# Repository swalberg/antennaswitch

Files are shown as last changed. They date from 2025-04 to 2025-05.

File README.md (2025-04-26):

# Remote antenna switch

This is a remote controller for one of those DIY antenna switch kits. It listens on Wifi for commands and controls the relays. They take a +12V signal to one of 4 relays with a common ground to pick which port is active, and ground the rest:

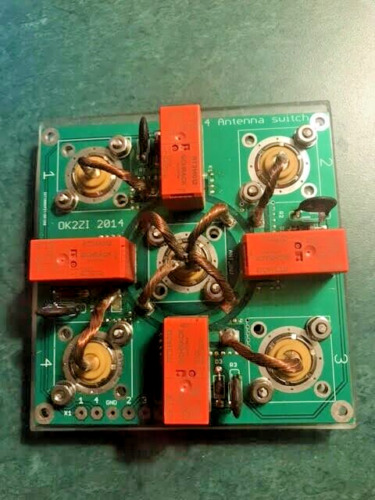
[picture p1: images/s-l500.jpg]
example antenna switch


The firmware for this allows both manual control, and to listen to N1MM+/RUMLogNG broadcasts to pick the band based on configured port/band combinations.

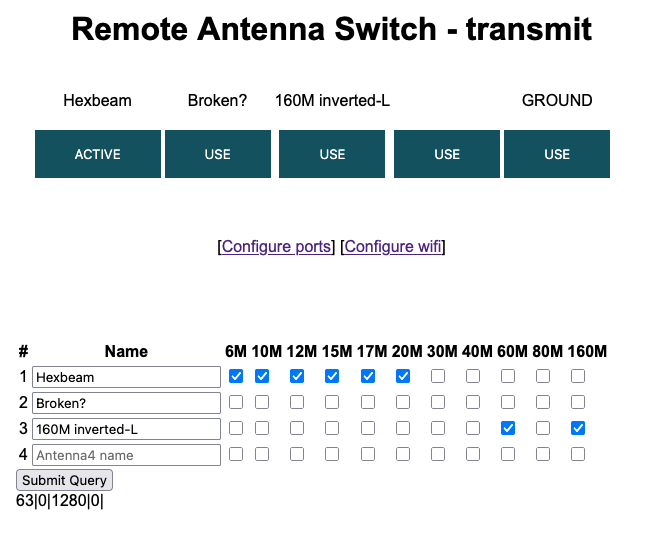
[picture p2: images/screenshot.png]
screenshots


When the device boots without a config it'll start a new AP for you to configure it.

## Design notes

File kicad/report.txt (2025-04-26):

Warning: Width correction constrained.  The width correction value must be in the range of [0.000001 mm; 0.199999 mm] for the current design rules.
Plotted to '/Users/sean/Documents/KiCad/8.0/projects/RemoteAntennaSwitch/outputs/RemoteAntennaSwitch-F_Cu.gbr'.
Plotted to '/Users/sean/Documents/KiCad/8.0/projects/RemoteAntennaSwitch/outputs/RemoteAntennaSwitch-B_Cu.gbr'.
Plotted to '/Users/sean/Documents/KiCad/8.0/projects/RemoteAntennaSwitch/outputs/RemoteAntennaSwitch-F_Paste.gbr'.
Plotted to '/Users/sean/Documents/KiCad/8.0/projects/RemoteAntennaSwitch/outputs/RemoteAntennaSwitch-B_Paste.gbr'.
Plotted to '/Users/sean/Documents/KiCad/8.0/projects/RemoteAntennaSwitch/outputs/RemoteAntennaSwitch-F_Silkscreen.gbr'.
Plotted to '/Users/sean/Documents/KiCad/8.0/projects/RemoteAntennaSwitch/outputs/RemoteAntennaSwitch-B_Silkscreen.gbr'.
Plotted to '/Users/sean/Documents/KiCad/8.0/projects/RemoteAntennaSwitch/outputs/RemoteAntennaSwitch-F_Mask.gbr'.
Plotted to '/Users/sean/Documents/KiCad/8.0/projects/RemoteAntennaSwitch/outputs/RemoteAntennaSwitch-B_Mask.gbr'.
Plotted to '/Users/sean/Documents/KiCad/8.0/projects/RemoteAntennaSwitch/outputs/RemoteAntennaSwitch-Edge_Cuts.gbr'.
Created Gerber job file '/Users/sean/Documents/KiCad/8.0/projects/RemoteAntennaSwitch/outputs/RemoteAntennaSwitch-job.gbrjob'.
Info: Done.

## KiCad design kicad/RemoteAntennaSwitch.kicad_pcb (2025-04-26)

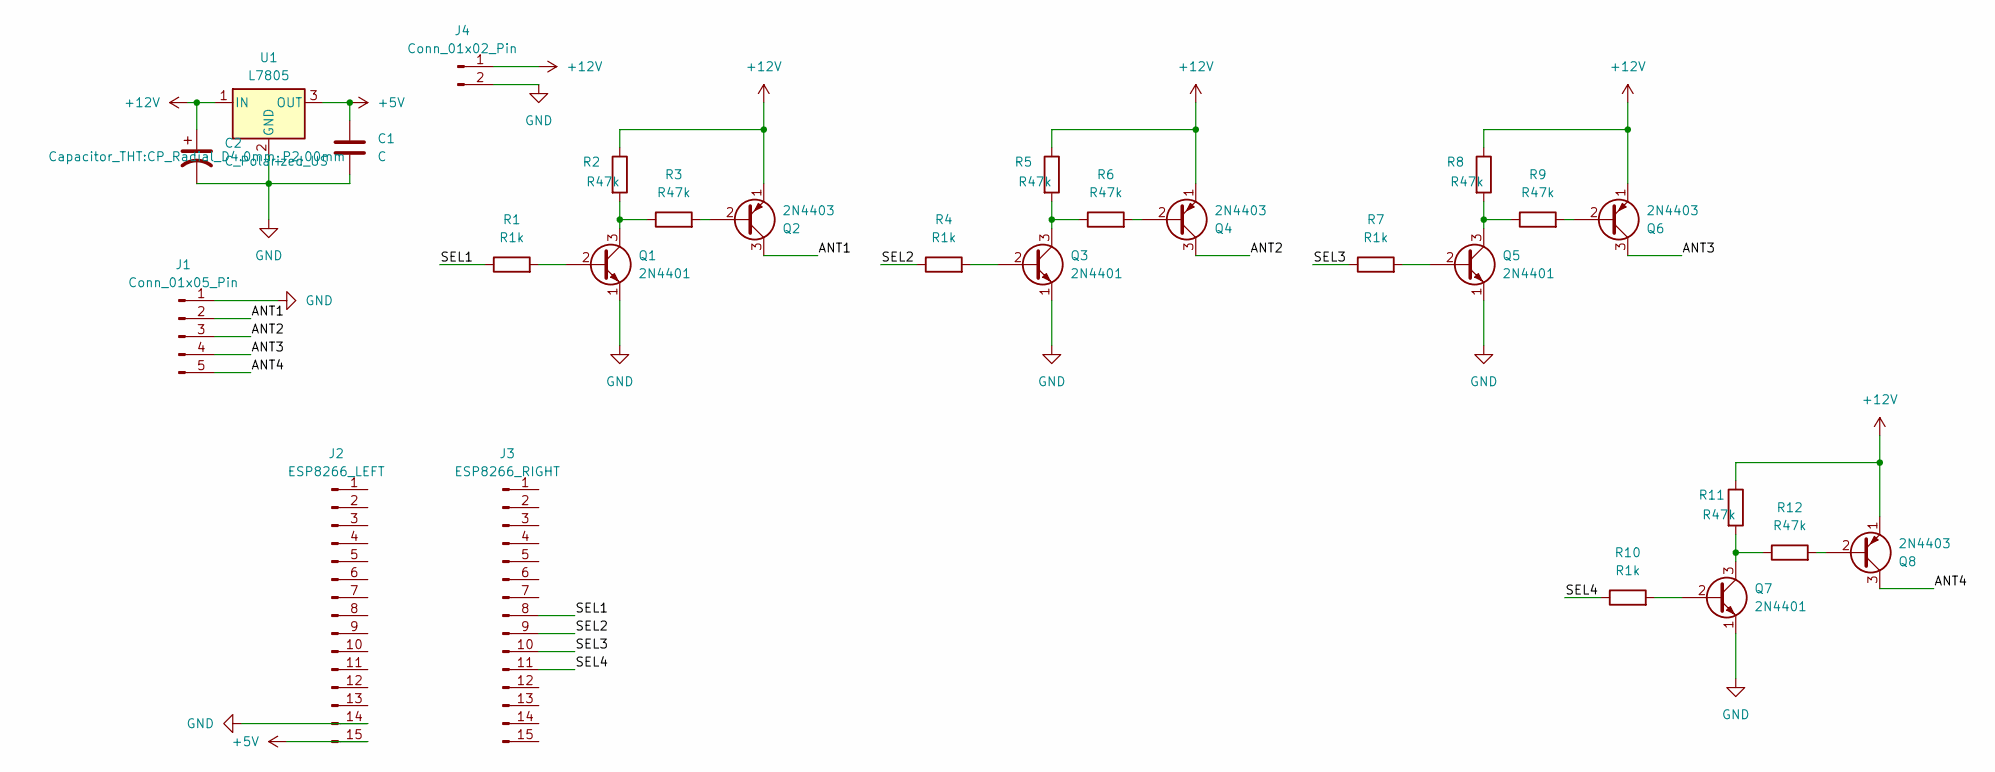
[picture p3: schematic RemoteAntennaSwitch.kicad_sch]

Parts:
C1: C; C_Disc_D3.0mm_W1.6mm_P2.50mm
C2: C_Polarized_US; CP_Radial_D4.0mm_P2.00mm
J1: Conn_01x05_Pin; JST_EH_B5B-EH-A_1x05_P2.50mm_Vertical
J2: ESP8266_LEFT; PinHeader_1x15_P1.00mm_Vertical
J3: ESP8266_RIGHT; PinHeader_1x15_P1.00mm_Vertical
J4: Conn_01x02_Pin; PinHeader_1x02_P1.00mm_Vertical
Q1, Q3, Q5, Q7: 2N4401; TO-92_Inline
Q2, Q4, Q6, Q8: 2N4403; TO-92_Inline
R1, R4, R7, R10: R1k; R_Axial_DIN0204_L3.6mm_D1.6mm_P1.90mm_Vertical
R2, R3, R5, R6, R8, R9, R11, R12: R47k; R_Axial_DIN0204_L3.6mm_D1.6mm_P1.90mm_Vertical
U1: L7805; TO-220-3_Vertical

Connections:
+5V: C1.1, J2.15, U1.3 (OUT)
+12V: C2.1, J4.1, Q2.1 (E), Q4.1 (E), Q6.1 (E), Q8.1 (E), R2.1, R5.1, R8.1, R11.1, U1.1 (IN)
/ANT1: J1.2, Q2.3 (C)
/ANT2: J1.3, Q4.3 (C)
/ANT3: J1.4, Q6.3 (C)
/ANT4: J1.5, Q8.3 (C)
/SEL1: J3.8, R1.1
/SEL2: J3.9, R4.1
/SEL3: J3.10, R7.1
/SEL4: J3.11, R10.1
GND: C1.2, C2.2, J1.1, J2.14, J4.2, Q1.1 (E), Q3.1 (E), Q5.1 (E), Q7.1 (E), U1.2 (GND)
unnamed: Q1.2 (B), R1.2
unnamed: Q1.3 (C), R2.2, R3.1
unnamed: Q2.2 (B), R3.2
unnamed: Q3.2 (B), R4.2
unnamed: Q3.3 (C), R5.2, R6.1
unnamed: Q4.2 (B), R6.2
unnamed: Q5.2 (B), R7.2
unnamed: Q5.3 (C), R8.2, R9.1
unnamed: Q6.2 (B), R9.2
unnamed: Q7.2 (B), R10.2
unnamed: Q7.3 (C), R11.2, R12.1
unnamed: Q8.2 (B), R12.2

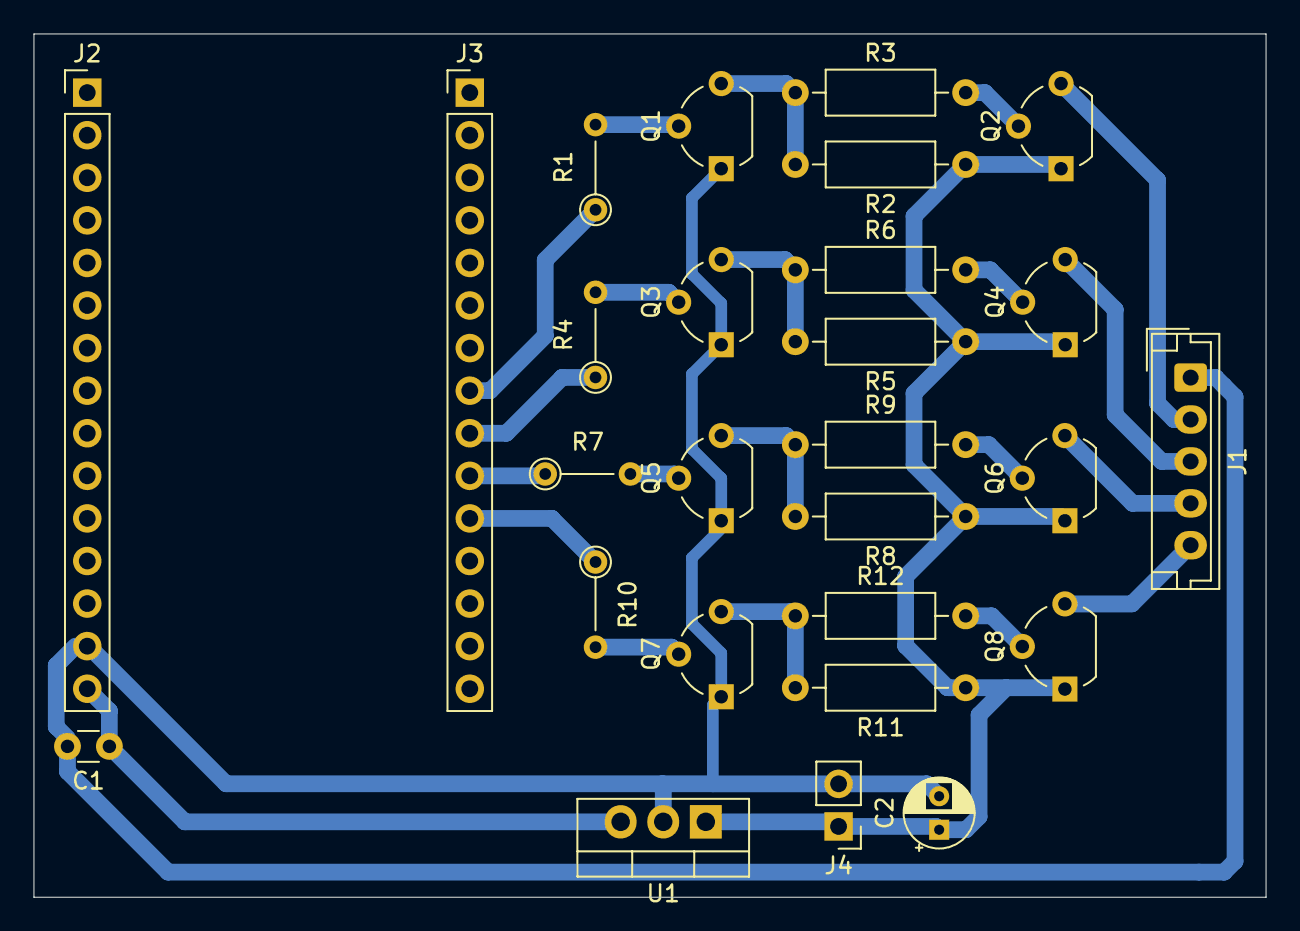
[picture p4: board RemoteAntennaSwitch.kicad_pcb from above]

Board: 2 copper layers, 73.5 x 51.5 mm, 27 parts (0 on the bottom side), 23 nets.

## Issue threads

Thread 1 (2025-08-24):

Doesn't work if it boots to no network

swalberg, 2025-08-24:
If there's a power outage then this device comes up before the wifi and just sits there in SoftAP mode. I have code in there to deal with it (I thought) but it doesn't seem to work.

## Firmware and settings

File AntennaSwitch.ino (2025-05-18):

#include <ArduinoOTA.h>
#include <EEPROM.h>
#include <ESP8266WiFi.h>
#include <ESPAsyncTCP.h>
#include <ESPAsyncWebServer.h>
#include <ESP8266mDNS.h>
#include <TinyXML.h>
#include <WebSerial.h>
#include <WiFiUdp.h>
#include "pages.h"

const int NUM_BANDS = 11;
enum Bands {
  B_6,
  B_10,
  B_12,
  B_15,
  B_17,
  B_20,
  B_30,
  B_40,
  B_60,
  B_80,
  B_160,
  B_unknown
};
Bands manualLocked = B_unknown;
Bands currentBand = B_unknown;

const int MAX_UDP_PACKET_SIZE = 255;
const unsigned long UNCONFIGURED_LIFE = 5 * 60 * 1000;  // 5 minute timer while unconfigured
WiFiUDP UDPInfo;
unsigned int localUdpPort = 12060;
char incomingPacket[MAX_UDP_PACKET_SIZE + 1];
TinyXML xml;
uint8_t buffer[150];  // For XML decoding
bool eligibleForRestart = false;

#define DEFAULT_HOSTNAME "antennaswitch1"
int pins[4] = { 15, 12, 14, 13 };  // The ports on the ESP8266 don't line up to the ports on the switcher because they're out of order and I didn't notice.
int LED = 2;
struct Antenna {
  char label[30];
  byte priority;
  int bands;
};

struct Configuration {
  char hostname[25];
  char ssid[32];
  char password[64];
  Antenna antennas[4];
} config;

// Set web server port number to 80
AsyncWebServer server(80);

int loops = 0;
int activePort = 0;

// Variable to store the HTTP request
String request;
String flashMessage;

void setup() {
  Serial.begin(115200);
  readConfig(config);
  WiFi.begin(config.ssid, config.password);
  for (int i = 0; i < 4; i++) {
    pinMode(pins[i], OUTPUT);
  }
  UDPInfo.begin(localUdpPort);
  // set up xml processing
  xml.init((uint8_t*)buffer, sizeof(buffer), &XML_callback);

  if (testWifi()) {
    Serial.println("Succesfully Connected!!!");
    // Print local IP address and start web server
    Serial.print("IP address: ");
    Serial.println(WiFi.localIP());
  } else {
    WiFi.mode(WIFI_STA);
    WiFi.disconnect();
    delay(100);
    WiFi.softAP("switchconfig", "");
    eligibleForRestart = true;
  }
  setupOta();
  setupRoutes();
  WebSerial.begin(&server);
  WebSerial.msgCallback(receiveSerialMessage);
  server.begin();
}

void loop() {
  ArduinoOTA.handle();
  handleXMLPacket();

  // If we've been sitting around in a state where we might have come up before wifi for too long, restart
  if (eligibleForRestart && millis() > UNCONFIGURED_LIFE) {
    ESP.reset();
  }
}

// If there's no value (default 255) in the first position, we've never been configured
bool isConfigured() {
  return EEPROM.read(0) != 255;
}

// are we connected to a wifi AP?
bool isWifiConnected() {
  return (WiFi.status() == WL_CONNECTED);
}

bool testWifi(void) {
  int c = 0;
  if (!isConfigured()) {
    return false;
  }

  Serial.println("Waiting for Wifi to connect");
  while (c < 20) {
    if (isWifiConnected()) {
      return true;
    }
    delay(500);
    Serial.print("*");
    c++;
  }
  Serial.println("");
  Serial.println("Connect timed out, opening AP");
  return false;
}

// UDP processing of port 12060
void handleXMLPacket() {
  // we've received something, so even if we're unconfigured, we must be on a network with a radio so don't restart automatically
  eligibleForRestart = false;

  int packetSize = UDPInfo.parsePacket();
  if (packetSize) {
    int len = UDPInfo.read(incomingPacket, MAX_UDP_PACKET_SIZE);
    xml.reset();
    for (int i = 0; i < len; i++) {
      xml.processChar(incomingPacket[i]);
    }
  }
}

void XML_callback(uint8_t statusflags, char* tagName, uint16_t tagNameLen, char* data, uint16_t dataLen) {
  if (!(statusflags & STATUS_TAG_TEXT)) {
    return;  // only care about getting the tag data
  }
  if (!strcasecmp(tagName, "/RadioInfo/Freq")) {
    WebSerial.printf("Received Packet to change to band %d which is antenna %d\n", band(atoi(data)), findBestAntenna(band(atoi(data))));
    currentBand = band(atoi(data));
    if (currentBand != manualLocked) {
      // switched bands on the radio, leave locked mode
      manualLocked = B_unknown;
      int antenna = findBestAntenna(currentBand);
      if (antenna >= 0) {
        WebSerial.printf("Switching to antenna %d\n", antenna);
        moveTo(antenna);
      }
    }
  }
}

int findBestAntenna(Bands band) {
  int c = 1 << band;
  for (int i = 0; i < 4; i++) {
    //WebSerial.printf("checking antenna %d which has bands %d against %d, result is %d\n", i, config.antennas[i].bands, c, config.antennas[i].bands & c);
    if ((config.antennas[i].bands & c) > 0) {
      return i;
    }
  }
  return -1;
}

// Web serial callback for input. Doesn't do anything for now
void receiveSerialMessage(uint8_t* data, size_t len) {
  WebSerial.println("Received Web Data...");
  String d = "";
  for (int i = 0; i < len; i++) {
    d += char(data[i]);
  }
  WebSerial.println(d);
}

void setupRoutes() {
  // Route for root / web page
  server.on("/", HTTP_GET, [](AsyncWebServerRequest* request) {
    request->send_P(200, "text/html", index_html, processor);
    WebSerial.println("Root page request");
  });

  server.on("/status.json", HTTP_GET, [](AsyncWebServerRequest* request) {
    request->send_P(200, "application/json", status_json, processor);
  });

  server.on("/config_wifi", HTTP_GET, [](AsyncWebServerRequest* request) {
    request->send_P(200, "text/html", config_wifi, wifi_processor);
  });
  server.on("/config_wifi", HTTP_POST, [](AsyncWebServerRequest* request) {
    if (request->hasParam("ssid", true) && request->hasParam("pass", true)) {
      strcpy(config.hostname, request->getParam("hostname", true)->value().c_str());
      strcpy(config.ssid, request->getParam("ssid", true)->value().c_str());
      strcpy(config.password, request->getParam("pass", true)->value().c_str());
      writeConfig(config);

      request->send(200, "application/json", "{\"Success\":\"saved to eeprom... resetting to boot into new wifi\"}");
      ESP.reset();
    } else {
      request->send(409, "application/json", "{\"Error\":\"Missing a ssid and password\"}");
    }
  });

  server.on("/config", HTTP_GET, [](AsyncWebServerRequest* request) {
    request->send_P(200, "text/html", config_html, processor);
  });

  server.on("/config", HTTP_POST, [](AsyncWebServerRequest* request) {
    for (int i = 0; i < 4; i++) {
      String rvar = "ant";
      rvar += i;
      // Label
      if (request->hasParam(rvar, true)) {
        strcpy(config.antennas[i].label, request->getParam(rvar, true)->value().c_str());
      }
      config.antennas[i].bands = 0;  // we only get in values that are set, so start from nothing and build up
      int c = 1;
      for (int b = 0; b < NUM_BANDS; b++) {
        String band = "band_";
        band += i;
        band += "_";
        band += b;
        if (request->hasParam(band, true)) {
          if (request->getParam(band, true)->value() == "on") {
            config.antennas[i].bands |= c;  // set the bit, we support this band.
          }
        }
        c *= 2;
      }
    }

    writeConfig(config);
    request->redirect("/config");
  });

  server.on("/change", HTTP_GET, [](AsyncWebServerRequest* request) {
    if (request->hasParam("ant")) {
      manualLocked = currentBand;  // Save the current band because we are locked to this antenna for this band
      moveTo(atoi(request->getParam("ant")->value().c_str()));
      WebSerial.println("Changing to " + request->getParam("ant")->value());
      request->send(200, "text/html", "{\"status\": \"ok\"}");
    } else {
      WebSerial.println("I got asked to move but no antenna given");
      request->send(412, "text/html", "{\"status\": \"need an antenna\"}");
    }
  });

  server.on("/debug", HTTP_GET, [](AsyncWebServerRequest* request) {
    request->send_P(200, "text/html", debug_html, processor);
  });

  server.on("/on", HTTP_GET, [](AsyncWebServerRequest* request) {
    manualLocked = currentBand;  // lock it!
    if (request->hasParam("ant")) {
      WebSerial.println("on - " + request->getParam("ant")->value());

      digitalWrite(pins[atoi(request->getParam("ant")->value().c_str())], HIGH);
      request->send(200, "text/html", "{\"status\": \"ok\"}");

    } else {
      request->send(412, "text/html", "{\"status\": \"need an antenna\"}");
    }
  });

  server.on("/off", HTTP_GET, [](AsyncWebServerRequest* request) {
    manualLocked = currentBand;  // lock it!
    if (request->hasParam("ant")) {
      WebSerial.println("off - " + request->getParam("ant")->value());
      digitalWrite(pins[atoi(request->getParam("ant")->value().c_str())], LOW);
      request->send(200, "text/html", "{\"status\": \"ok\"}");

    } else {
      request->send(412, "text/html", "{\"status\": \"need an antenna\"}");
    }
  });
}
void moveTo(int port) {
  WebSerial.printf("> %d\n", port);
  for (int i = 0; i < 4; i++) {
    digitalWrite(pins[i], port == i ? HIGH : LOW);
  }
  activePort = port;
}

// Replaces placeholders in a page with dynamic info
String processor(const String& var) {

  if (var == "ANTENNA0") { return String(config.antennas[0].label); }
  if (var == "ANTENNA1") { return String(config.antennas[1].label); }
  if (var == "ANTENNA2") { return String(config.antennas[2].label); }
  if (var == "ANTENNA3") { return String(config.antennas[3].label); }
  if (var == "ANTENNA0BANDS") { return checkboxes(0); }
  if (var == "ANTENNA1BANDS") { return checkboxes(1); }
  if (var == "ANTENNA2BANDS") { return checkboxes(2); }
  if (var == "ANTENNA3BANDS") { return checkboxes(3); }
  if (var == "ACTIVE_NUMBER") { return String(activePort); }
  if (var == "SWITCH_NAME") { return String("transmit"); }
  if (var == "FLASH_MESSAGE") { return String(flashMessage); }
  if (var == "MANUAL") { return manualLocked == B_unknown ? "false" : "true"; }
  if (var == "DEBUG") {
    String d = "";
    for (int i = 0; i < 4; i++) {
      d += config.antennas[i].bands;
      d += "|";
    }
    return d;
  }

  return String();  // default
}

// template vars for wifi setup
String wifi_processor(const String& var) {
  if (var == "FOUND_NETWORKS") {
    return String("Network scanning disabled...");
  }
  if (var == "xxxFOUND_NETWORKS") {
    int n = WiFi.scanNetworks();
    Serial.printf("There are %d networks\n", n);
    if (n == 0) {
      Serial.println("no networks found");
      return String("No networks found.");
    } else {
      String foundNetworks = String("<ol>");
      for (int i = 0; i < n; i++) {
        // Print SSID and RSSI for each network found
        foundNetworks += "<li>";
        foundNetworks += WiFi.SSID(i);
        foundNetworks += " (";
        foundNetworks += WiFi.RSSI(i);

        foundNetworks += ")";
        foundNetworks += (WiFi.encryptionType(i) == ENC_TYPE_NONE) ? " " : "*";
        foundNetworks += "</li>";
      }
      foundNetworks += "</ol>";
      return (foundNetworks);
    }
  }

  return String();  //default
}

String checkboxes(int ant) {
  String out = "";
  int c = 1;  // compare bit
  for (int i = 0; i < NUM_BANDS; i++) {
    String value = "";

    if ((config.antennas[ant].bands & c) > 0) {
      value += "checked";
    }
    out += String("<td><input type=\"checkbox\" name =\"band_");
    out += ant;
    out += "_";
    out += i;
    out += "\" " + value + "></td>";
    c *= 2;
  }
  return out;
}

void setupOta() {
  // Hostname defaults to esp8266-[ChipID]
  ArduinoOTA.setHostname(getHostname());

  // No authentication by default
  // ArduinoOTA.setPassword((const char *)"123");

  ArduinoOTA.onStart([]() {
    Serial.println("Start");
  });
  ArduinoOTA.onEnd([]() {
    Serial.println("\nEnd");
  });
  ArduinoOTA.onProgress([](unsigned int progress, unsigned int total) {
    Serial.printf("Progress: %u%%\r", (progress / (total / 100)));
  });
  ArduinoOTA.onError([](ota_error_t error) {
    Serial.printf("Error[%u]: ", error);
    if (error == OTA_AUTH_ERROR) Serial.println("Auth Failed");
    else if (error == OTA_BEGIN_ERROR) Serial.println("Begin Failed");
    else if (error == OTA_CONNECT_ERROR) Serial.println("Connect Failed");
    else if (error == OTA_RECEIVE_ERROR) Serial.println("Receive Failed");
    else if (error == OTA_END_ERROR) Serial.println("End Failed");
  });
  ArduinoOTA.begin();
}

char* getHostname() {
  if (config.hostname == "") {
    strcpy(config.hostname, DEFAULT_HOSTNAME);
  }
  return config.hostname;
}

void readConfig(Configuration& config) {
  EEPROM.begin(512);
  EEPROM.get(0, config);
}

void writeConfig(Configuration& config) {
  EEPROM.put(0, config);
  EEPROM.commit();
}

void allOff() {
  for (int i = 0; i < 4; i++) {
    digitalWrite(pins[i], LOW);
  }
}

Bands band(int freq) {
  // Freq is in 10Hz, so 180740 is 1.807.40 on the dial
  freq = freq / 100;  // drop the last digit
  if (freq >= 50000) {
    return B_6;
  }
  if (freq >= 28000) {
    return B_10;
  }
  if (freq >= 24890) {
    return B_12;
  }
  if (freq >= 24890) {
    return B_12;
  }
  if (freq >= 21000) {
    return B_15;
  }
  if (freq >= 18068) {
    return B_17;
  }
  if (freq >= 14000) {
    return B_20;
  }
  if (freq >= 10100) {
    return B_30;
  }
  if (freq >= 7000) {
    return B_40;
  }
  if (freq >= 5330) {
    return B_60;
  }
  if (freq >= 3500) {
    return B_80;
  }
  if (freq >= 1800) {
    return B_160;
  }
  return B_unknown;
}

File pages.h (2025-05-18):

const char status_json[] PROGMEM = R"rawliteral(
  {
    "active": %ACTIVE_NUMBER%,
    "antennas": [
      "%ANTENNA0%", "%ANTENNA1%", "%ANTENNA2%", "%ANTENNA3%", "%ANTENNA4%"
    ],
    "manual": %MANUAL%,
    "debug": "%DEBUG%"
  }

)rawliteral";

const char config_wifi[] PROGMEM = R"rawliteral(
<!DOCTYPE HTML>
  <html>Hello from ESP8266 at %IPADDR%!!!
  <p>%FOUND_NETWORKS%</p>
  <form method='post' action='/config_wifi'>
  <label>SSID: </label><input name='ssid' length=32>
  <label>Password: </label><input name='pass' length=64>
  <label>Hostname</label><input name='hostname'><input type='submit'></form>
  </html>
)rawliteral";

const char config_html[] PROGMEM = R"rawliteral(
<!DOCTYPE HTML><html>
<head>
  <title>Antenna switch</title>
  <meta name="viewport" content="width=device-width, initial-scale=1">
  <link rel="icon" href="data:,">
  <style>
    html {font-family: Arial;}
  </style>
</head>
<body>
  <form action="/config" method="POST">
    <table>
    <tr><th>#</th><th>Name</th><th>6M</th><th>10M</th><th>12M</th><th>15M</th><th>17M</th><th>20M</th><th>30M</th><th>40M</th><th>60M</th><th>80M</th><th>160M</th></tr>
    <tr><td><label for="ant0">1</label></td><td><input type="text" name="ant0" value="%ANTENNA0%" placeholder="Antenna1 name">%ANTENNA0BANDS%</tr>
    <tr><td><label for="ant1">2</label></td><td><input type="text" name="ant1" value="%ANTENNA1%" placeholder="Antenna2 name">%ANTENNA1BANDS%</tr>
    <tr><td><label for="ant2">3</label></td><td><input type="text" name="ant2" value="%ANTENNA2%" placeholder="Antenna3 name">%ANTENNA2BANDS%</tr>
    <tr><td><label for="ant3">4</label></td><td><input type="text" name="ant3" value="%ANTENNA3%" placeholder="Antenna4 name">%ANTENNA3BANDS%</tr>
    </table>
    <div><input type="submit"></div>
  </form>
</body>
</html>
)rawliteral";

const char index_html[] PROGMEM = R"rawliteral(
<!DOCTYPE HTML><html>
<head>
  <title>Antenna switch</title>
  <meta name="viewport" content="width=device-width, initial-scale=1">
  <link rel="icon" href="data:,">
  <style>
    html {font-family: Arial; display: inline-block; text-align: center;}
    h2 {font-size: 3.0rem;}
    xxp {font-size: 3.0rem;}
    body {max-width: 600px; margin:0px auto; padding-bottom: 25px;}
    .button { background-color: #195B6A; border: none; color: white; padding: 16px 40px;}
    .button2 {background-color: #77878A;}
    .redbg { background-color: red;}
  </style>
</head>
<body>
  <h1>Remote Antenna Switch - %SWITCH_NAME%</h1>
  <h2>%FLASH_MESSAGE%</h2>
  <table>
  <tr><td>%ANTENNA0%</td><td>%ANTENNA1%</td><td>%ANTENNA2%</td><td>%ANTENNA3%</td><td>GROUND</td></tr>
    <tr><td><p><a href="#"><button class="button" id="0" onClick="change(this)">USE</button></a></p></td>
    <td><p><a href="#"><button class="button" id="1" onClick="change(this)">USE</button></a></p></td>
    <td><p><a href="#"><button class="button" id="2" onClick="change(this)">USE</button></a></p></td>
    <td><p><a href="#"><button class="button" id="3" onClick="change(this)">USE</button></a></p></td>
    <td><p><a href="#"><button class="button" id="99" onClick="change(this)">USE</button></a></p></td></tr>
  
  </table>
  <h2 id="motorStatus"></h2>
  <h3 id="debug"></h3>
  <p>[<a href="/config">Configure ports</a>] [<a href="/config_wifi">Configure wifi</a>]</p>
  <script>
  function change(el) {
    var xhr = new XMLHttpRequest();
    console.log(el);
    console.log(el.id);
    xhr.open("GET", "/change?ant=" + el.id);
    xhr.send();
  }

  setInterval(function () {
    var req = new XMLHttpRequest();
    req.responseType = 'json';
    req.open('GET', "/status.json", true);
    req.onload  = function() {
      var j = req.response;
    
      Array.from(document.getElementsByClassName("button")).forEach(
        function(element, index, array) {
          if (index == j.active) {
            if (j.manual) {
              element.innerHTML = "LOCKED";
            } else {
              element.innerHTML = "ACTIVE";
            }
            element.class = "button button2";
          } else {
            element.innerHTML = "USE";
            element.class = "button";
          }
        }
      );
    };
    req.send();
  }, 2000);

  </script>
</body>
</html>
)rawliteral";


const char debug_html[] PROGMEM = R"rawliteral(
<!DOCTYPE HTML><html>
<head>
  <title>Antenna switch</title>
  <meta name="viewport" content="width=device-width, initial-scale=1">
  <link rel="icon" href="data:,">
  <style>
    html {font-family: Arial; display: inline-block; text-align: center;}
    h2 {font-size: 3.0rem;}
    xxp {font-size: 3.0rem;}
    body {max-width: 600px; margin:0px auto; padding-bottom: 25px;}
    .button { background-color: #195B6A; border: none; color: white; padding: 16px 40px;}
    .button2 {background-color: #77878A;}
    .redbg { background-color: red;}
  </style>
</head>
<body>
  <h1>Remote Antenna Switch - %SWITCH_NAME%</h1>
  <h2>%FLASH_MESSAGE%</h2>
  <table>
  <tr><td>%ANTENNA0%</td><td>%ANTENNA1%</td><td>%ANTENNA2%</td><td>%ANTENNA3%</td><td>GROUND</td></tr>
    <tr><td><p><a href="#"><button class="button" id="on0" onClick="on(0)">ON</button></a></p></td>
    <td><p><a href="#"><button class="button" id="on1" onClick="on(1)">ON</button></a></p></td>
    <td><p><a href="#"><button class="button" id="on2" onClick="on(2)">ON</button></a></p></td>
    <td><p><a href="#"><button class="button" id="on3" onClick="on(3)">ON</button></a></p></td></tr>  

    <tr><td><p><a href="#"><button class="button" id="off0" onClick="off(0)">OFF</button></a></p></td>
    <td><p><a href="#"><button class="button" id="off1" onClick="off(1)">OFF</button></a></p></td>
    <td><p><a href="#"><button class="button" id="off2" onClick="off(2)">OFF</button></a></p></td>
    <td><p><a href="#"><button class="button" id="off3" onClick="off(3)">OFF</button></a></p></td></tr>  
  </table>
  <h3 id="debug"></h3>
  <script>
  function on(id) {
    var xhr = new XMLHttpRequest();
    xhr.open("GET", "/on?ant=" + id);
    xhr.send();
  }

  function off(id) {
    var xhr = new XMLHttpRequest();
    xhr.open("GET", "/off?ant=" + id);
    xhr.send();
  }

  </script>
</body>
</html>
)rawliteral";

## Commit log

2024-04-24 Move pages to separate file and fixing way we parse input
    Been so long I don't remember :(
    [AntennaSwitch.ino, pages.h]
2024-12-04 Use the new relay switch
    Got a new antenna switch based on relays, so stop using the stepper
    motor version
2024-12-05 I forgot to set the pins to output
    Also cleaned up antenna switching logic
2025-04-26 Finish moving everything to one loop
    Something's not quite working in config_wifi, it seems to crash.
    Something to do with network scanning, the ESP resets
    Not in a position to console in to get a stack trace now.
    guess I don't need this
    [AntennaSwitch.ino, pages.h]
2025-04-26 Add kicad files
    [RemoteAntennaSwitch.kicad_pcb, RemoteAntennaSwitch.kicad_sch]
2025-04-27 Add a reset
    If I have a power outage these guys come up before the wifi, so sit on
    the unconfigured network until I walk downstairs to restart them. This
    adds a watchdog timer; if we booted and didn't see our configured
    network in 5 minutes and have not received anything on port 12060 then
    restart
    [AntennaSwitch.ino, pages.h]
2025-05-15 Add a locked mode
    If you pick an antenna on the web then that selection is locked until
    the band on the radio changes.
2025-05-18 Adding a debug mode to be able to test the relays
